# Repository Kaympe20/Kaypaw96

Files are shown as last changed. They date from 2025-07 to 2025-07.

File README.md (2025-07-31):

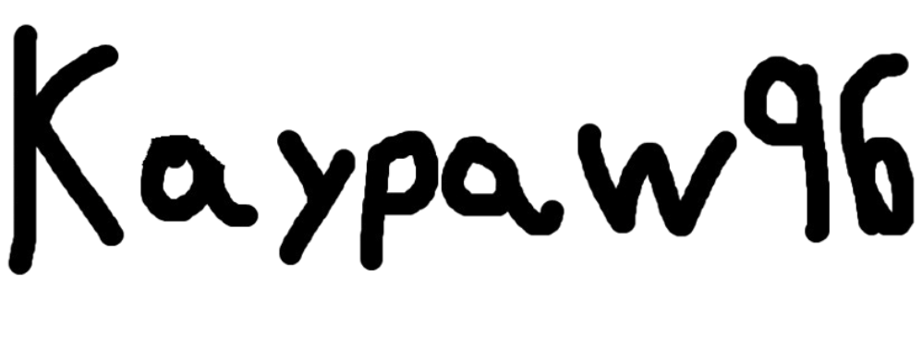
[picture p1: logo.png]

# Kaypaw96

<br>

A Southpaw 96% keyboard because numpads on the left are awesome
* They allow the keyboard to be centered on your desk.
* They let you use the mouse and numpad at the same time.
* They are plain more ergonomic.

---

[As featured on](https://highway.hackclub.com/projects/kaympe20/kaypaw96)

[](https://highway.hackclub.com/projects/kaympe20/kaypaw96)

---

I made this keyboard because, as an ambidextrous person, I often feel like my left hand is under-utilized while I am doing productivity, coding, and gaming. I also use a 75% and sometimes miss having more keys, so I wanted to make a keyboard that gave you nearly every key of a regular keyboard, plus 4 additional macro keys for things like sleep.

## Pics











## CAD

The entire CAD workspace can be found on [Onshape](https://cad.onshape.com/documents/bc15378757c65db7b8fb3e3b/w/9f716e622823b7e5e5c4b7e3/e/b78d5af8ee98cae8cd027468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)

## BOM

| Item | Quantity | Price | Price After Taxes + Shipping |
|---|---|---|---|
[Assembled PCB](https://github.com/Kaympe20/Kaypaw96/tree/main/production) | 1 | $81.58 | $169.13
[3D Printed Case](https://github.com/Kaympe20/Kaypaw96/blob/main/cad/Case.step) | 1 | $0 | $0
[Cherry MX Switches](https://www.amazon.com/Glorious-Gaming-Hotswappable-Mechanical-Keyboards/dp/B0DCPCS6CP) (cheapest I could find after shipping) | 110 | $31.99 | $33.91
[Keycap Set](https://www.amazon.com/Keycaps-Doubleshot-Percent-Mechanical-Keyboard/dp/B0D1QVD55F) | 1 | $16.86 | $17.87
[NCP1117-3.3_SOT223](https://www.amazon.com/PMMCON-AMS1117-LM1117-Voltage-Regulator/dp/B0BNY8KM87) | 1 | $9.99 | $10.59
[M3 Hardware](https://www.amazon.com/420pcs-Premium-Printing-Assortment-Washers/dp/B0CSX4NX7R) | N/a | $6.99 | $7.41

Total: $238.91

Here's the parts I selected in JLCPCB:



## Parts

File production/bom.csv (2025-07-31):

Designator | Footprint | Quantity | Value | LCSC Part #
C1, C2 | C0402 | 2 | 15p
C10, C11, C12, C13, C14, C16, C6, C7, C8, C9 | C0402 | 10 | 100n
C100, C101, C102, C103, C104, C105, C106, C107, C109, C110, C111, C112, C113, C114, C115, C116, C117, C118, C25, C26, C27, C28, C29, C30, C40, C41, C42, C43, C44, C45, C55, C56, C57, C58, C59, C60, C70, C71, C72, C73, C74, C75, C84, C85, C86, C87, C88, C89, C90, C96, C97, C98, C99 | C0402 | 53 | 0.1u
C15, C5 | C0402 | 2 | 1u
C3, C4 | C0402 | 2 | 10u
D1, D10, D100, D101, D102, D103, D104, D105, D11, D12, D13, D14, D15, D16, D17, D18, D19, D2, D20, D21, D22, D23, D24, D25, D26, D27, D28, D29, D3, D30, D31, D32, D33, D34, D35, D36, D37, D38, D39, D4, D40, D41, D42, D43, D44, D45, D46, D47, D48, D49, D5, D50, D51, D52, D53, D54, D55, D56, D57, D58, D59, D6, D60, D61, D62, D63, D64, D65, D66, D67, D68, D69, D7, D70, D71, D72, D73, D74, D75, D76, D77, D78, D79, D8, D80, D81, D82, D83, D84, D85, D86, D87, D88, D89, D9, D90, D91, D92, D93, D94, D95, D96, D97, D98, D99 | RB161QS-40 | 105 | D
D106, D107, D108, D109, D110, D111, D112, D113, D114, D115, D116, D117, D118, D119, D120, D121, D122, D123, D124, D125, D126, D127, D128, D129, D130, D131, D132, D133, D134, D135, D136, D137, D138, D139, D140, D141, D142, D143, D144, D145, D146, D147, D148, D149, D150, D151, D152, D153, D154, D155, D156, D157, D158, D159, D160, D161, D162, D163, D164, D165, D166, D167, D168, D169, D170, D171, D172, D173, D174, D175, D176, D177, D178, D179, D180, D181, D182, D183, D184, D185, D186, D187, D188, D189, D190, D191, D192, D193, D194, D195, D196, D197, D198, D199, D200, D201, D202, D203, D204, D205, D206, D207, D208, D209, D210 | SK6812MINI-E | 105 | SK6812MINI
J1 | USB_C_Receptacle_XKB_U262-16XN-4BVC11 | 1 | USB_C_Receptacle_USB2.0_14P
J2 | HDR-TH_2P-P2.54-V-M | 1 | Conn_01x02
R1, R6 | 0402 | 2 | 1k
R2, R3 | 0402 | 2 | 5.1k
R4, R5 | 0402 | 2 | 27.4
SW1, SW10, SW100, SW101, SW102, SW103, SW104, SW105, SW11, SW12, SW13, SW14, SW15, SW16, SW17, SW18, SW19, SW2, SW20, SW21, SW22, SW23, SW24, SW25, SW26, SW27, SW28, SW29, SW3, SW30, SW31, SW32, SW33, SW34, SW35, SW37, SW38, SW39, SW4, SW40, SW41, SW43, SW44, SW45, SW46, SW47, SW48, SW49, SW5, SW50, SW51, SW52, SW53, SW54, SW55, SW56, SW57, SW58, SW59, SW6, SW60, SW61, SW62, SW63, SW64, SW65, SW66, SW67, SW68, SW69, SW7, SW70, SW71, SW72, SW73, SW75, SW76, SW77, SW78, SW79, SW8, SW82, SW83, SW84, SW85, SW86, SW87, SW88, SW89, SW9, SW90, SW91, SW92, SW93, SW94, SW95, SW96, SW97, SW98 | SW_Cherry_MX_1.00u_PCB | 99 | SW_Push_45deg
SW36, SW74, SW81 | SW_Cherry_MX_2.00u_PCB | 3 | SW_Push_45deg
SW42, SW80 | SW_Cherry_MX_2.00u_Vertical_PCB | 2 | SW_Push_45deg
SW99 | SW_Cherry_MX_6.25u_PCB | 1 | SW_Push_45deg
U1 | QFN-56-1EP_7x7mm_P0.4mm_EP3.2x3.2mm | 1 | RP2040
U2 | SOT-223-3_TabPin2 | 1 | NCP1117-3.3_SOT223
U3 | SOIC-8_5.3x5.3mm_P1.27mm | 1 | W25Q128JVS
Y1 | XTAL_ABM8-272-T3 | 1 | ABM8-272-T3

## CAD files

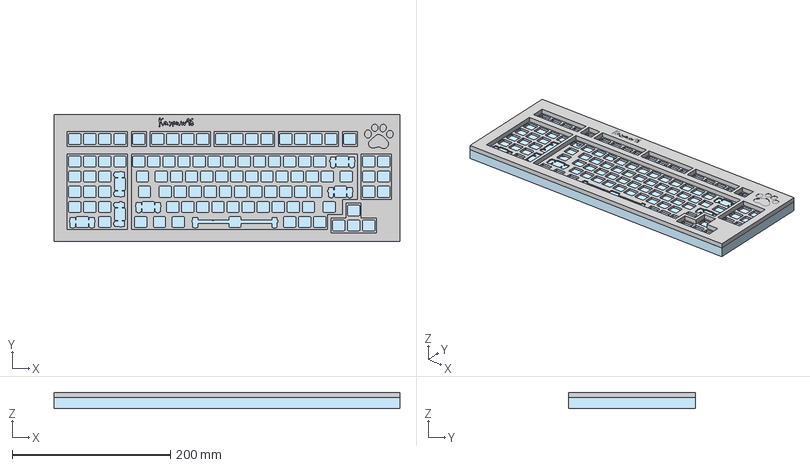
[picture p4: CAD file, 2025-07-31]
cad/Case.step
437.1 x 160.4 x 20.4 mm

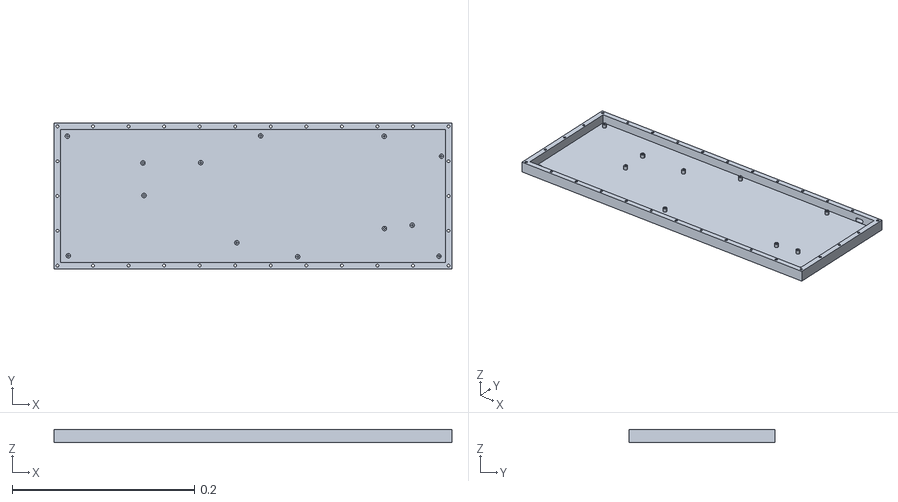
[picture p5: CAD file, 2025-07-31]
cad/STL/Case - Bottom.stl
0.437 x 0.16 x 0.0138

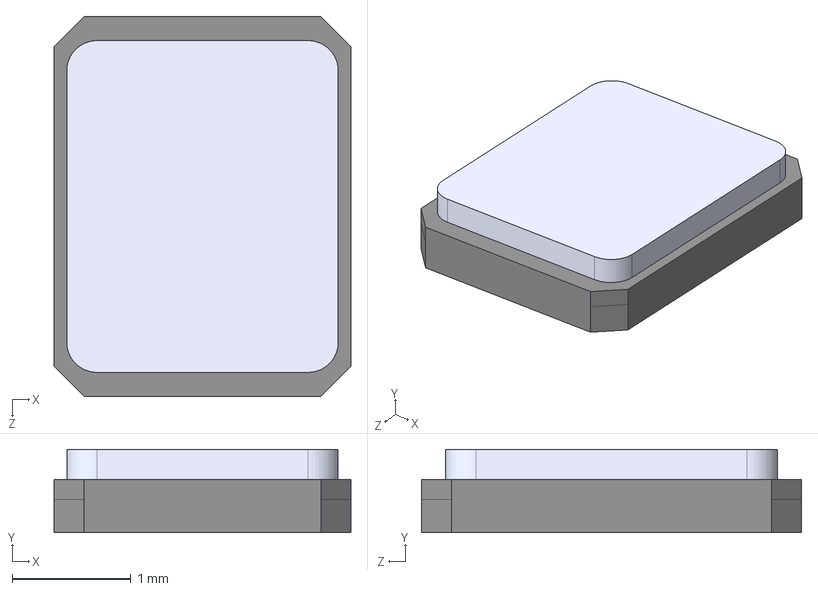
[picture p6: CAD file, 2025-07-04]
pcb/imports/ABM8-272-T3/ABM8-272-T3.step
2.50 x 0.7 x 3.20 mm

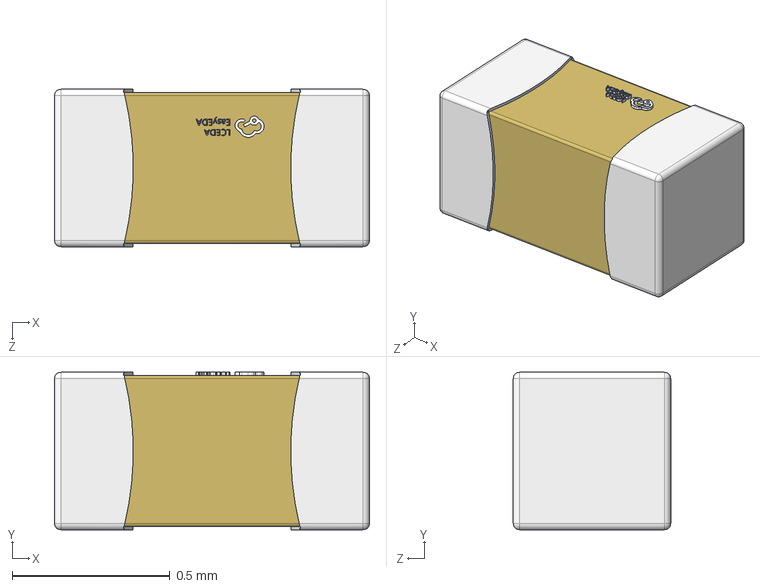
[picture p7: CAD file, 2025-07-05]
pcb/imports/CC0402FRNPO9BN150/C0402_L1.0-W0.5-H0.5.step
1.00 x 0.5 x 0.5 mm

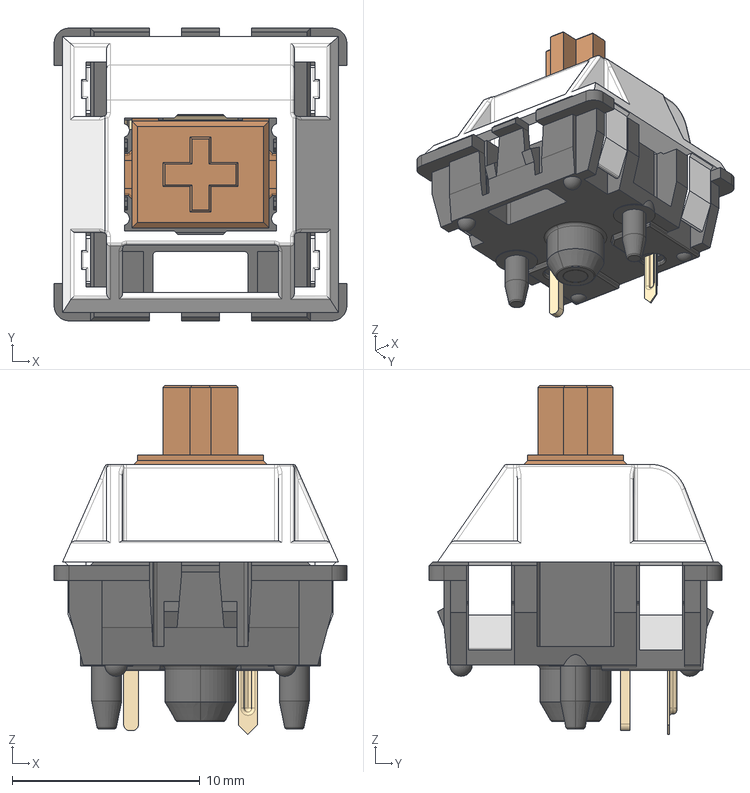
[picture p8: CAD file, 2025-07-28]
pcb/imports/Cherry MX Switch/SW_Cherry_MX_PCB.stp
15.6 x 15.6 x 18.6 mm

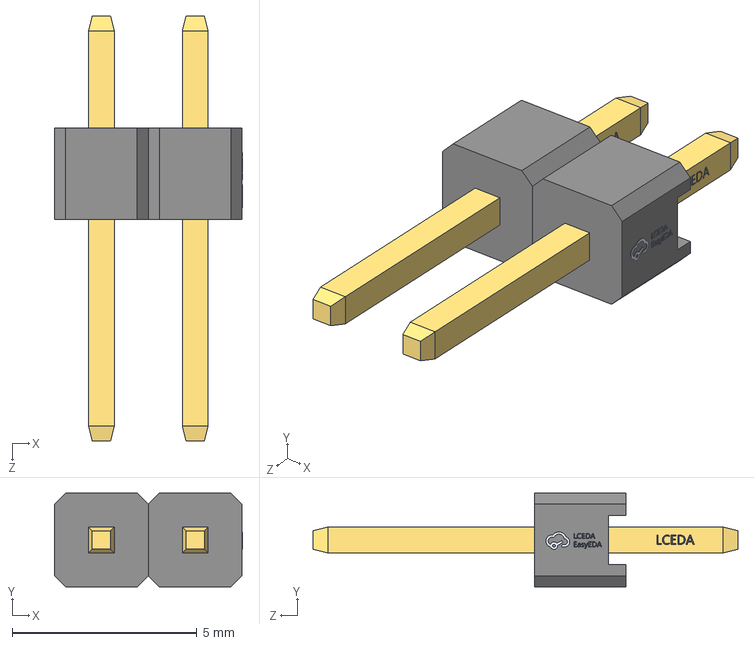
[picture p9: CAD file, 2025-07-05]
pcb/imports/PZ254V-11-02P/HDR2.54-M-LI-1X2P.step
5.09 x 2.54 x 11.5 mm

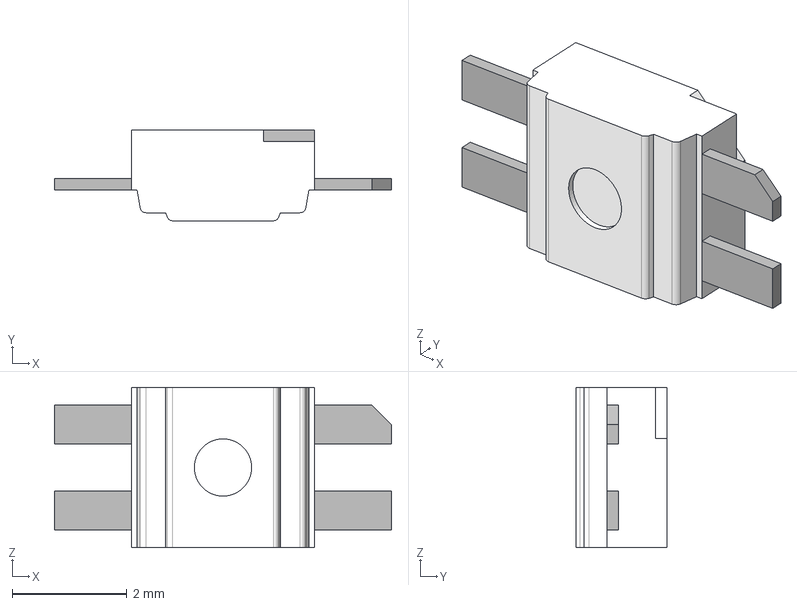
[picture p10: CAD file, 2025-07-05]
pcb/imports/SK6812-MINI Reverse/SK6812MINI-E.step
5.88 x 1.58 x 2.80 mm

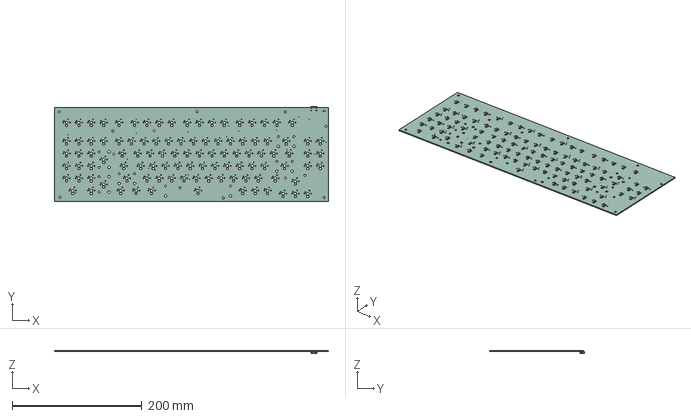
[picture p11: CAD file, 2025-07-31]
pcb/PCB.step
421.9 x 147.0 x 4.85 mm
USB-3.1-SMD_16P-L8.9-W7.3-H3.3-P0.5
kaypaw96_PCB

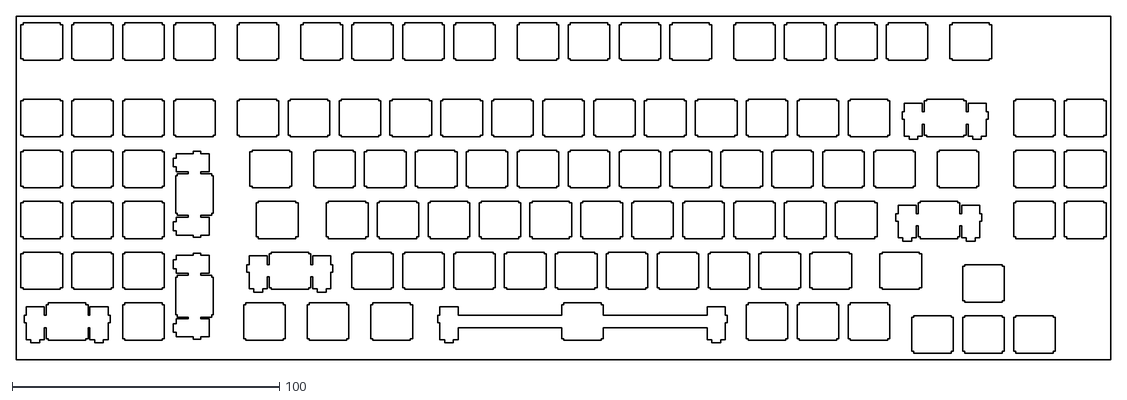
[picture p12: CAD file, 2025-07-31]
plate.dxf
409.6 x 128.6

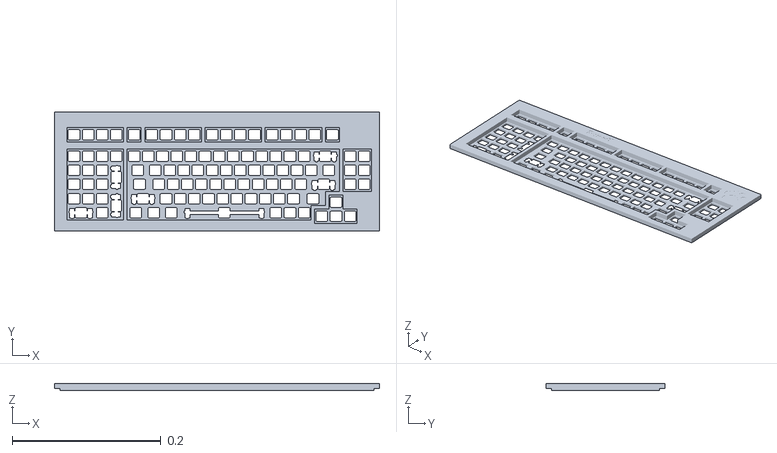
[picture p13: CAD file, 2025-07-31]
cad/STL/Case - Top.stl
0.437 x 0.16 x 0.0096

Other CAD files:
pcb/PCB without components.step

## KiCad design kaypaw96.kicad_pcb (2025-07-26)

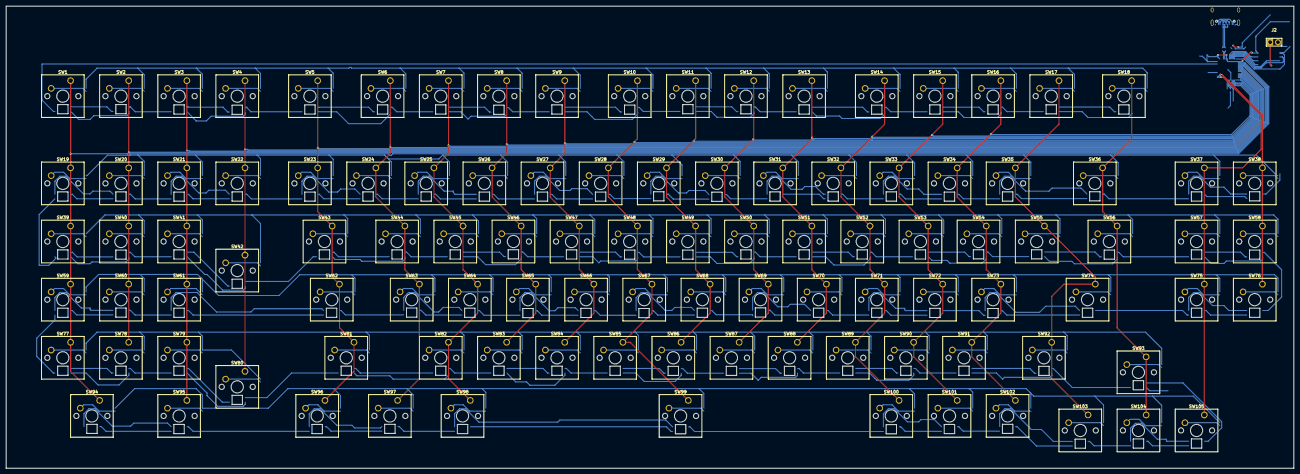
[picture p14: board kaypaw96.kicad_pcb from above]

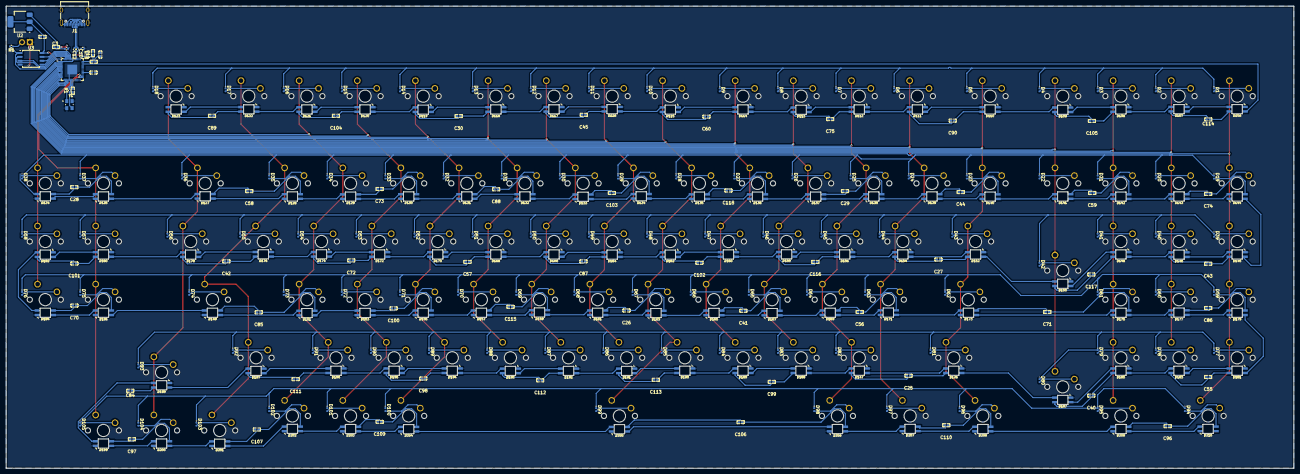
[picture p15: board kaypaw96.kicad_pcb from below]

Board: 2 copper layers, 421.9 x 151.4 mm, 388 parts (282 on the bottom side), 256 nets.

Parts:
C3: 10u; C0402
C8, C9, C10, C11, C12, C13, C14: 100n; C0402
C25, C26, C27, C28, C29, C30, C40, C41, C42, C43, C44, C45, C55, C56, C57, C58, C59, C60, C70, C71, C72, C73, C74, C75, C84, C85, C86, C87, C88, C89, C90, C96, C97, C98, C99, C100, C101, C102, C103, C104, C105, C106, C107, C109, C110, C111, C112, C113, C114, C115, C116, C117, C118: 0.1u; C0402
D1, D2, D3, D4, D5, D6, D7, D8, D9, D10, D11, D12, D13, D14, D15, D16, D17, D18, D19, D20, D21, D22, D23, D24, D25, D26, D27, D28, D29, D30, D31, D32, D33, D34, D35, D36, D37, D38, D39, D40, D41, D42, D43, D44, D45, D46, D47, D48, D49, D50, D51, D52, D53, D54, D55, D56, D57, D58, D59, D60, D61, D62, D63, D64, D65, D66, D67, D68, D69, D70, D71, D72, D73, D74, D75, D76, D77, D78, D79, D80, D81, D82, D83, D84, D85, D86, D87, D88, D89, D90, D91, D92, D93, D94, D95, D96, D97, D98, D99, D100, D101, D102, D103, D104, D105: D; RB161QS-40
D106, D107, D108, D109, D110, D111, D112, D113, D114, D115, D116, D117, D118, D119, D120, D121, D122, D123, D124, D125, D126, D127, D128, D129, D130, D131, D132, D133, D134, D135, D136, D137, D138, D139, D140, D141, D142, D143, D144, D145, D146, D147, D148, D149, D150, D151, D152, D153, D154, D155, D156, D157, D158, D159, D160, D161, D162, D163, D164, D165, D166, D167, D168, D169, D170, D171, D172, D173, D174, D175, D176, D177, D178, D179, D180, D181, D182, D183, D184, D185, D186, D187, D188, D189, D190, D191, D192, D193, D194, D195, D196, D197, D198, D199, D200, D201, D202, D203, D204, D205, D206, D207, D208, D209, D210: SK6812MINI; SK6812MINI-E
J1: USB_C_Receptacle_USB2.0_14P; USB_C_Receptacle_XKB_U262-16XN-4BVC11
J2: Conn_01x02; HDR-TH_2P-P2.54-V-M
R1, R6: 1k; R_0402_1005Metric
R2, R3: 5.1k; R_0402_1005Metric
R4, R5: 27.4; R_0402_1005Metric
SW1, SW2, SW3, SW4, SW5, SW6, SW7, SW8, SW9, SW10, SW11, SW12, SW13, SW14, SW15, SW16, SW17, SW18, SW19, SW20, SW21, SW22, SW23, SW24, SW25, SW26, SW27, SW28, SW29, SW30, SW31, SW32, SW33, SW34, SW35, SW36, SW37, SW38, SW39, SW40, SW41, SW42, SW43, SW44, SW45, SW46, SW47, SW48, SW49, SW50, SW51, SW52, SW53, SW54, SW55, SW56, SW57, SW58, SW59, SW60, SW61, SW62, SW63, SW64, SW65, SW66, SW67, SW68, SW69, SW70, SW71, SW72, SW73, SW74, SW75, SW76, SW77, SW78, SW79, SW80, SW81, SW82, SW83, SW84, SW85, SW86, SW87, SW88, SW89, SW90, SW91, SW92, SW93, SW94, SW95, SW96, SW97, SW98, SW99, SW100, SW101, SW102, SW103, SW104, SW105: SW_Push_45deg; SW_Cherry_MX_1.00u_PCB
U1: RP2040; QFN-56-1EP_7x7mm_P0.4mm_EP3.2x3.2mm
U2: NCP1117-3.3_SOT223; SOT-223-3_TabPin2
U3: W25Q128JVS; SOIC-8_5.3x5.3mm_P1.27mm
Y1: ABM8-272-T3; XTAL_ABM8-272-T3

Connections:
+1V1: U1.23 (DVDD), U1.45 (VREG_VOUT), U1.50 (DVDD)
+3.3V: C8.1, C9.1, C10.1, C11.1, C12.1, C13.1, C14.1, U1.1 (IOVDD), U1.10 (IOVDD), U1.22 (IOVDD), U1.33 (IOVDD), U1.42 (IOVDD), U1.43 (ADC_AVDD), U1.44 (VREG_IN), U1.48 (USB_VDD), U1.49 (IOVDD), U2.2 (VO), U3.8 (VCC)
+5V: C3.1, C25.1, C26.1, C27.1, C28.1, C29.1, C30.1, C40.1, C41.1, C42.1, C43.1, C44.1, C45.1, C55.1, C56.1, C57.1, C58.1, C59.1, C60.1, C70.1, C71.1, C72.1, C73.1, C74.1, C75.1, C84.1, C85.1, C86.1, C87.1, C88.1, C89.1, C90.1, C96.1, C97.1, C98.1, C99.1, C100.1, C101.1, C102.1, C103.1, C104.1, C105.1, C106.1, C107.1, C109.1, C110.1, C111.1, C112.1, C113.1, C114.1, C115.1, C116.1, C117.1, C118.1, D106.4 (VDD), D107.4 (VDD), D108.4 (VDD), D109.4 (VDD), D110.4 (VDD), D111.4 (VDD), D112.4 (VDD), D113.4 (VDD), D114.4 (VDD), D115.4 (VDD), D116.4 (VDD), D117.4 (VDD), D118.4 (VDD), D119.4 (VDD), D120.4 (VDD), D121.4 (VDD), D122.4 (VDD), D123.4 (VDD), D124.4 (VDD), D125.4 (VDD), D126.4 (VDD), D127.4 (VDD), D128.4 (VDD), D129.4 (VDD), D130.4 (VDD), D131.4 (VDD), D132.4 (VDD), D133.4 (VDD), D134.4 (VDD), D135.4 (VDD), D136.4 (VDD), D137.4 (VDD), D138.4 (VDD), D139.4 (VDD), D140.4 (VDD), D141.4 (VDD), D142.4 (VDD), D143.4 (VDD), D144.4 (VDD), D145.4 (VDD), D146.4 (VDD), D147.4 (VDD), D148.4 (VDD), D149.4 (VDD), D150.4 (VDD), D151.4 (VDD), D152.4 (VDD), D153.4 (VDD), D154.4 (VDD), D155.4 (VDD), D156.4 (VDD), D157.4 (VDD), D158.4 (VDD), D159.4 (VDD), D160.4 (VDD), D161.4 (VDD), D162.4 (VDD), D163.4 (VDD), D164.4 (VDD), D165.4 (VDD), D166.4 (VDD), D167.4 (VDD), D168.4 (VDD), D169.4 (VDD), D170.4 (VDD), D171.4 (VDD), D172.4 (VDD), D173.4 (VDD), D174.4 (VDD), D175.4 (VDD), D176.4 (VDD), D177.4 (VDD), D178.4 (VDD), D179.4 (VDD), D180.4 (VDD), D181.4 (VDD), D182.4 (VDD), D183.4 (VDD), D184.4 (VDD), D185.4 (VDD), D186.4 (VDD), D187.4 (VDD), D188.4 (VDD), D189.4 (VDD), D190.4 (VDD), D191.4 (VDD), D192.4 (VDD), D193.4 (VDD), D194.4 (VDD), D195.4 (VDD), D196.4 (VDD), D197.4 (VDD), D198.4 (VDD), D199.4 (VDD), D200.4 (VDD), D201.4 (VDD), D202.4 (VDD), D203.4 (VDD), D204.4 (VDD), D205.4 (VDD), D206.4 (VDD), D207.4 (VDD), D208.4 (VDD), D209.4 (VDD), D210.4 (VDD), J1.A4 (VBUS), J1.A9 (VBUS), J1.B4 (VBUS), J1.B9 (VBUS), U2.3 (VI)
/QSPI_SCLK: U1.52 (QSPI_SCLK), U3.6 (CLK)
/QSPI_SD0: U1.53 (QSPI_SD0), U3.5 (DI/IO_{0})
/QSPI_SD1: U1.55 (QSPI_SD1), U3.2 (DO/IO_{1})
/QSPI_SD2: U1.54 (QSPI_SD2), U3.3 (~WP/IO_{2})
/QSPI_SD3: U1.51 (QSPI_SD3), U3.7 (~HOLD/~RESET/IO_{3})
/QSPI_SS: R6.2, U1.56 (QSPI_SS), U3.1 (~CS)
Col 1: SW1.1, SW19.1, SW39.1, SW59.1, SW77.1, SW94.1, U1.2 (GPIO0)
Col 2: SW2.1, SW20.1, SW40.1, SW60.1, SW78.1, U1.3 (GPIO1)
Col 3: SW3.1, SW21.1, SW41.1, SW61.1, SW79.1, SW95.1, U1.4 (GPIO2)
Col 4: SW4.1, SW22.1, SW42.1, SW80.1, U1.5 (GPIO3)
Col 5: SW5.1, SW23.1, SW43.1, SW62.1, SW81.1, SW96.1, U1.6 (GPIO4)
Col 6: SW6.1, SW24.1, SW44.1, SW63.1, SW97.1, U1.7 (GPIO5)
Col 7: SW7.1, SW25.1, SW45.1, SW64.1, SW82.1, SW98.1, U1.8 (GPIO6)
Col 8: SW8.1, SW26.1, SW46.1, SW65.1, SW83.1, U1.9 (GPIO7)
Col 9: SW9.1, SW27.1, SW47.1, SW66.1, SW84.1, U1.11 (GPIO8)
Col 10: SW10.1, SW28.1, SW48.1, SW67.1, SW85.1, SW99.1, U1.12 (GPIO9)
Col 11: SW11.1, SW29.1, SW49.1, SW68.1, SW86.1, U1.13 (GPIO10)
Col 12: SW12.1, SW30.1, SW50.1, SW69.1, SW87.1, U1.14 (GPIO11)
Col 13: SW13.1, SW31.1, SW51.1, SW70.1, SW88.1, U1.15 (GPIO12)
Col 14: SW14.1, SW32.1, SW52.1, SW71.1, SW89.1, SW100.1, U1.16 (GPIO13)
Col 15: SW15.1, SW33.1, SW53.1, SW72.1, SW90.1, SW101.1, U1.17 (GPIO14)
Col 16: SW16.1, SW34.1, SW54.1, SW73.1, SW91.1, SW102.1, U1.18 (GPIO15)
Col 17: SW17.1, SW35.1, SW55.1, SW74.1, SW92.1, SW103.1, U1.27 (GPIO16)
Col 18: SW18.1, SW36.1, SW56.1, SW93.1, SW104.1, U1.28 (GPIO17)
Col 19: SW37.1, SW57.1, SW75.1, SW105.1, U1.29 (GPIO18)
Col 20: SW38.1, SW58.1, SW76.1, U1.30 (GPIO19)
D+: J1.A6 (D+), J1.B6 (D+), R4.1
D-: J1.A7 (D-), J1.B7 (D-), R5.1
GND: C3.2, C8.2, C9.2, C10.2, C11.2, C12.2, C13.2, C14.2, C25.2, C26.2, C27.2, C28.2, C29.2, C30.2, C40.2, C41.2, C42.2, C43.2, C44.2, C45.2, C55.2, C56.2, C57.2, C58.2, C59.2, C60.2, C70.2, C71.2, C72.2, C73.2, C74.2, C75.2, C84.2, C85.2, C86.2, C87.2, C88.2, C89.2, C90.2, C96.2, C97.2, C98.2, C99.2, C100.2, C101.2, C102.2, C103.2, C104.2, C105.2, C106.2, C107.2, C109.2, C110.2, C111.2, C112.2, C113.2, C114.2, C115.2, C116.2, C117.2, C118.2, D106.2 (VSS), D107.2 (VSS), D108.2 (VSS), D109.2 (VSS), D110.2 (VSS), D111.2 (VSS), D112.2 (VSS), D113.2 (VSS), D114.2 (VSS), D115.2 (VSS), D116.2 (VSS), D117.2 (VSS), D118.2 (VSS), D119.2 (VSS), D120.2 (VSS), D121.2 (VSS), D122.2 (VSS), D123.2 (VSS), D124.2 (VSS), D125.2 (VSS), D126.2 (VSS), D127.2 (VSS), D128.2 (VSS), D129.2 (VSS), D130.2 (VSS), D131.2 (VSS), D132.2 (VSS), D133.2 (VSS), D134.2 (VSS), D135.2 (VSS), D136.2 (VSS), D137.2 (VSS), D138.2 (VSS), D139.2 (VSS), D140.2 (VSS), D141.2 (VSS), D142.2 (VSS), D143.2 (VSS), D144.2 (VSS), D145.2 (VSS), D146.2 (VSS), D147.2 (VSS), D148.2 (VSS), D149.2 (VSS), D150.2 (VSS), D151.2 (VSS), D152.2 (VSS), D153.2 (VSS), D154.2 (VSS), D155.2 (VSS), D156.2 (VSS), D157.2 (VSS), D158.2 (VSS), D159.2 (VSS), D160.2 (VSS), D161.2 (VSS), D162.2 (VSS), D163.2 (VSS), D164.2 (VSS), D165.2 (VSS), D166.2 (VSS), D167.2 (VSS), D168.2 (VSS), D169.2 (VSS), D170.2 (VSS), D171.2 (VSS), D172.2 (VSS), D173.2 (VSS), D174.2 (VSS), D175.2 (VSS), D176.2 (VSS), D177.2 (VSS), D178.2 (VSS), D179.2 (VSS), D180.2 (VSS), D181.2 (VSS), D182.2 (VSS), D183.2 (VSS), D184.2 (VSS), D185.2 (VSS), D186.2 (VSS), D187.2 (VSS), D188.2 (VSS), D189.2 (VSS), D190.2 (VSS), D191.2 (VSS), D192.2 (VSS), D193.2 (VSS), D194.2 (VSS), D195.2 (VSS), D196.2 (VSS), D197.2 (VSS), D198.2 (VSS), D199.2 (VSS), D200.2 (VSS), D201.2 (VSS), D202.2 (VSS), D203.2 (VSS), D204.2 (VSS), D205.2 (VSS), D206.2 (VSS), D207.2 (VSS), D208.2 (VSS), D209.2 (VSS), D210.2 (VSS), J1.A1 (GND), J1.A12 (GND), J1.B1 (GND), J1.B12 (GND), J1.S1 (SHIELD), J2.1, R2.2, R3.2, U1.19 (TESTEN), U1.57 (GND), U2.1 (GND), U3.4 (GND), Y1.2 (GND), Y1.4 (GND)
NEO: D106.3 (DIN), U1.40 (GPIO28_ADC2)
unnamed: R1.1, Y1.3
unnamed: D1.2 (A), SW1.2
unnamed: D2.2 (A), SW2.2
unnamed: D3.2 (A), SW3.2
unnamed: D4.2 (A), SW4.2
unnamed: D5.2 (A), SW5.2
unnamed: D6.2 (A), SW6.2
unnamed: D7.2 (A), SW7.2
unnamed: D8.2 (A), SW8.2
unnamed: D9.2 (A), SW9.2
unnamed: D10.2 (A), SW10.2
unnamed: D11.2 (A), SW11.2
unnamed: D12.2 (A), SW12.2
unnamed: D13.2 (A), SW13.2
unnamed: D14.2 (A), SW14.2
unnamed: D15.2 (A), SW15.2
unnamed: D16.2 (A), SW16.2
unnamed: D17.2 (A), SW17.2
unnamed: D18.2 (A), SW18.2
unnamed: D19.2 (A), SW19.2
unnamed: D20.2 (A), SW20.2
unnamed: D21.2 (A), SW21.2
unnamed: D22.2 (A), SW22.2
unnamed: D23.2 (A), SW23.2
unnamed: D24.2 (A), SW24.2
unnamed: D25.2 (A), SW25.2
unnamed: D26.2 (A), SW26.2
unnamed: D27.2 (A), SW27.2
unnamed: D28.2 (A), SW28.2
unnamed: D29.2 (A), SW29.2
unnamed: D30.2 (A), SW30.2
unnamed: D31.2 (A), SW31.2
unnamed: D32.2 (A), SW32.2
unnamed: D33.2 (A), SW33.2
unnamed: D34.2 (A), SW34.2
unnamed: D35.2 (A), SW35.2
unnamed: D36.2 (A), SW36.2
unnamed: D37.2 (A), SW37.2
unnamed: D38.2 (A), SW38.2
unnamed: D39.2 (A), SW39.2
unnamed: D40.2 (A), SW40.2
unnamed: D41.2 (A), SW41.2
unnamed: D42.2 (A), SW42.2
unnamed: D43.2 (A), SW43.2
unnamed: D44.2 (A), SW44.2
unnamed: D45.2 (A), SW45.2
unnamed: D46.2 (A), SW46.2
unnamed: D47.2 (A), SW47.2
unnamed: D48.2 (A), SW48.2
unnamed: D49.2 (A), SW49.2
unnamed: D50.2 (A), SW50.2
unnamed: D51.2 (A), SW51.2
unnamed: D52.2 (A), SW52.2
unnamed: D53.2 (A), SW53.2
unnamed: D54.2 (A), SW54.2
unnamed: D55.2 (A), SW55.2
unnamed: D56.2 (A), SW56.2
unnamed: D57.2 (A), SW57.2
unnamed: D58.2 (A), SW58.2
unnamed: D59.2 (A), SW59.2
unnamed: D60.2 (A), SW60.2
unnamed: D61.2 (A), SW61.2
unnamed: D62.2 (A), SW62.2
unnamed: D63.2 (A), SW63.2
unnamed: D64.2 (A), SW64.2
unnamed: D65.2 (A), SW65.2
unnamed: D66.2 (A), SW66.2
unnamed: D67.2 (A), SW67.2
unnamed: D68.2 (A), SW68.2
unnamed: D69.2 (A), SW69.2
unnamed: D70.2 (A), SW70.2
unnamed: D71.2 (A), SW71.2
unnamed: D72.2 (A), SW72.2
unnamed: D73.2 (A), SW73.2
unnamed: D74.2 (A), SW74.2
unnamed: D75.2 (A), SW75.2
unnamed: D76.2 (A), SW76.2
unnamed: D77.2 (A), SW77.2
unnamed: D78.2 (A), SW78.2
unnamed: D79.2 (A), SW79.2
unnamed: D80.2 (A), SW80.2
unnamed: D81.2 (A), SW81.2
unnamed: D82.2 (A), SW82.2
unnamed: D83.2 (A), SW83.2
unnamed: D84.2 (A), SW84.2
unnamed: D85.2 (A), SW85.2
unnamed: D86.2 (A), SW86.2
unnamed: D87.2 (A), SW87.2
unnamed: D88.2 (A), SW88.2
unnamed: D89.2 (A), SW89.2
unnamed: D90.2 (A), SW90.2
unnamed: D91.2 (A), SW91.2
unnamed: D92.2 (A), SW92.2
unnamed: D93.2 (A), SW93.2
unnamed: D94.2 (A), SW94.2
unnamed: D95.2 (A), SW95.2
unnamed: D96.2 (A), SW96.2
unnamed: D97.2 (A), SW97.2
unnamed: D98.2 (A), SW98.2
unnamed: D99.2 (A), SW99.2
unnamed: D100.2 (A), SW100.2
unnamed: D101.2 (A), SW101.2
unnamed: D102.2 (A), SW102.2
unnamed: D103.2 (A), SW103.2
unnamed: D104.2 (A), SW104.2
unnamed: D105.2 (A), SW105.2
unnamed: D106.1 (DOUT), D107.3 (DIN)
unnamed: D107.1 (DOUT), D108.3 (DIN)
unnamed: D108.1 (DOUT), D109.3 (DIN)
unnamed: D109.1 (DOUT), D110.3 (DIN)
unnamed: D110.1 (DOUT), D111.3 (DIN)
unnamed: D111.1 (DOUT), D112.3 (DIN)
unnamed: D112.1 (DOUT), D113.3 (DIN)
unnamed: D113.1 (DOUT), D114.3 (DIN)
unnamed: D114.1 (DOUT), D115.3 (DIN)
unnamed: D115.1 (DOUT), D116.3 (DIN)
unnamed: D116.1 (DOUT), D117.3 (DIN)
unnamed: D117.1 (DOUT), D118.3 (DIN)
unnamed: D118.1 (DOUT), D119.3 (DIN)
unnamed: D119.1 (DOUT), D120.3 (DIN)
unnamed: D120.1 (DOUT), D121.3 (DIN)
unnamed: D121.1 (DOUT), D122.3 (DIN)
unnamed: D122.1 (DOUT), D123.3 (DIN)
unnamed: D123.1 (DOUT), D124.3 (DIN)
unnamed: D124.1 (DOUT), D125.3 (DIN)
unnamed: D125.1 (DOUT), D127.3 (DIN)
unnamed: D126.3 (DIN), D187.1 (DOUT)
unnamed: D126.1 (DOUT), D147.3 (DIN)
unnamed: D127.1 (DOUT), D128.3 (DIN)
unnamed: D128.1 (DOUT), D129.3 (DIN)
unnamed: D129.1 (DOUT), D130.3 (DIN)
unnamed: D130.1 (DOUT), D131.3 (DIN)
unnamed: D131.1 (DOUT), D132.3 (DIN)
unnamed: D132.1 (DOUT), D133.3 (DIN)
unnamed: D133.1 (DOUT), D134.3 (DIN)
unnamed: D134.1 (DOUT), D135.3 (DIN)
unnamed: D135.1 (DOUT), D136.3 (DIN)
unnamed: D136.1 (DOUT), D137.3 (DIN)
unnamed: D137.1 (DOUT), D138.3 (DIN)
unnamed: D138.1 (DOUT), D139.3 (DIN)
unnamed: D139.1 (DOUT), D140.3 (DIN)
unnamed: D140.1 (DOUT), D141.3 (DIN)
unnamed: D141.1 (DOUT), D142.3 (DIN)
unnamed: D142.1 (DOUT), D143.3 (DIN)
unnamed: D143.1 (DOUT), D144.3 (DIN)
unnamed: D144.1 (DOUT), D145.3 (DIN)
unnamed: D145.1 (DOUT), D146.3 (DIN)
unnamed: D146.1 (DOUT), D148.3 (DIN)
unnamed: D147.1 (DOUT), D188.3 (DIN)
unnamed: D148.1 (DOUT), D150.3 (DIN)
unnamed: D149.3 (DIN), D186.1 (DOUT)
unnamed: D149.1 (DOUT), D151.3 (DIN)
unnamed: D150.1 (DOUT), D152.3 (DIN)
unnamed: D151.1 (DOUT), D153.3 (DIN)
unnamed: D152.1 (DOUT), D154.3 (DIN)
unnamed: D153.1 (DOUT), D155.3 (DIN)
unnamed: D154.1 (DOUT), D156.3 (DIN)
unnamed: D155.1 (DOUT), D157.3 (DIN)
unnamed: D156.1 (DOUT), D158.3 (DIN)
unnamed: D157.1 (DOUT), D159.3 (DIN)
unnamed: D158.1 (DOUT), D160.3 (DIN)
unnamed: D159.1 (DOUT), D161.3 (DIN)
unnamed: D160.1 (DOUT), D162.3 (DIN)
unnamed: D161.1 (DOUT), D163.3 (DIN)
unnamed: D162.1 (DOUT), D164.3 (DIN)
unnamed: D163.1 (DOUT), D165.3 (DIN)
unnamed: D164.1 (DOUT), D166.3 (DIN)
unnamed: D165.1 (DOUT), D167.3 (DIN)
unnamed: D166.1 (DOUT), D168.3 (DIN)
unnamed: D167.1 (DOUT), D169.3 (DIN)
unnamed: D168.1 (DOUT), D170.3 (DIN)
unnamed: D169.1 (DOUT), D171.3 (DIN)
unnamed: D170.1 (DOUT), D172.3 (DIN)
unnamed: D171.1 (DOUT), D173.3 (DIN)
unnamed: D172.1 (DOUT), D174.3 (DIN)
unnamed: D173.1 (DOUT), D175.3 (DIN)
unnamed: D174.1 (DOUT), D176.3 (DIN)
unnamed: D175.1 (DOUT), D177.3 (DIN)
unnamed: D176.1 (DOUT), D178.3 (DIN)
unnamed: D177.1 (DOUT), D179.3 (DIN)
unnamed: D178.1 (DOUT), D180.3 (DIN)
unnamed: D179.1 (DOUT), D181.3 (DIN)
unnamed: D180.1 (DOUT), D182.3 (DIN)
unnamed: D181.1 (DOUT), D183.3 (DIN)
unnamed: D182.1 (DOUT), D184.3 (DIN)
unnamed: D183.1 (DOUT), D185.3 (DIN)
unnamed: D184.1 (DOUT), D186.3 (DIN)
unnamed: D185.1 (DOUT), D187.3 (DIN)
unnamed: D188.1 (DOUT), D189.3 (DIN)
unnamed: D189.1 (DOUT), D190.3 (DIN)
unnamed: D190.1 (DOUT), D191.3 (DIN)
unnamed: D191.1 (DOUT), D192.3 (DIN)
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

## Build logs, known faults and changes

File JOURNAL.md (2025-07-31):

---
title: "Kaypaw96"
author: "Kayla Blosser aka @Kayla"
description: "A southpaw 96% keyboard"
created_at: "2024-07-03"
---

### **Total Time Spent: 43hr**

---

## July 4, 2025

I setup the layout using [keyboard-layout-editor](https://keyboard-layout-editor.com/)



Time Spent: 1hr

---

I created the basic layout of the keyswitches in the schematic after learning how matrixes work



... only to realize I need diodes.



Time Spent: 2hr

---

I wired up the matrix with labels



Time Spent: 1.5hr

---

The pico didn't have enough pins so I've begun work directly using the RP2040 using the [RP2040 hardware design datasheet](https://datasheets.raspberrypi.com/rp2040/hardware-design-with-rp2040.pdf).



Time Spent 3hr

---

I finished up the setup for the RP2040 including power delivery, USB communications, and 



Time Spent: 3.5 hr

---

I research JLC PCBA Extended and added all of the neopixels on a single pin that will draw 1.3A.



Time Spent: 1.5hr

---

## July 5, 2025

I got a dark theme to stop searing my eyes and got capacitors for the NeoPixels, as well as having to figure out that 0.1uF is the same as 100nF.



Time Spent: 2hr

---

I found 0805 capacitors of varying capcity on [LCSC](https://lcsc.com/), imported them using [`easyeda2kicad`](https://github.com/uPesy/easyeda2kicad.py). I then assigned each type to its respective item, before realizing that the ESR of 0805 capacitors is too much for the RP2040 and that I would need 0402 alternatives. After going back to get the diodes, I couldn't find footprints so I had to slightly modify the template 0402 footprint.



Time Spent: 3.5hr

---

I started designing the PCB and started the grueling wiring of each individual key and light. I want to cry 😢. My fingers and my soul are in pain.



Time Spent: 2.5hr

---

I finished adding all of the neopixels, all 105 of them 😢.



Time Spent: 1.5hr

---

## July 6, 2025

I added more capacitors as per the spec of the SK6812-MINI's... 52 of them. I love KiCAD 👍.



Time Spent: 1.5hr

---

## July 25, 2025

I started wiring everything to do with the microcontrollers and all of its additional parts. It got hectic and chaotic very quickly.



[@marios](https://github.com/GalaxyGamingBoy) recomended I do a ground pour so I used [my hackpad v2 docs backup](https://hackpad-v2-backup.pages.dev/advancedguide#ground%20pour) to learn how to do one and it started looking much better.



I then started on the rows and collumns, but was again having difficulty in figuring out how to route them without vias because they ruin signal integrity. Then I realized that the keys are binary and signal integrity/noise shouldn't be nearly enough to get to on from off. With that newfound knowledge, I routed all of them using at least 2 vias each.



Here's what the microcontroller section looks like:



Time Spent: 4.5 hr

---

## July 26, 2025

I finished the PCB!!!! 🎊🥳💃🎉📢📣 (almost, tomorrow I'll figure out the hole size I need for gasket mounting)

I did all of the requisite wiring and looked thorugh all of my DRC checkers to see if there was any major issues.

As per [@mra](https://github.com/MichaByte)'s suggestion, I set the ground fill to both sides and put in a bunch of vias to connect all of the unconnected areas (that I had to constantly change to no layers to check where the unconnected areas were).

I now have 0 unconnected areas, except for the sides of my heart, which is now broken after spending so much time on a keyboard that might not work.



I also had to add a few more decoupling capacitors as per the spec, which, as always, required a lot of rerouting.



Time Spent: 3.5hr

---

## July 27, 2025

I finished the mounting holes and added holes for stabalizers. Originally I wanted to forego using screws and wanted to do a gasket mounting setup, but with cost quickly becoming something I have to look out for, I'll leave the mounting holes, and get poron foam to laser cut at my local library should there be room in the budget.





Time Spent: 1hr

---

## July 29, 2025

I added some more mounting holes and altered the size to be much better matched to the actual size of m3 screws.



I also began CAD and started trying to figure out how to add a plate for my switches.



Time Spent: 1.5hr

---

The holes were intersecting the stabalizers so I changed the position which required redoing half of the work I did.







While I was working on that, I decided to go and switch the measurements to variables to allow me to change them *en mas* later if tolerances don't allow.



The grey "𝑓𝑥" indicates they are calculated instead of a set variable.

Time Spent: 2hr

---

## July 30, 2025

I looked at Joe Scotto's How to Design Mechanical Keyboard Plates and Cases [as reccomended by the hackpad guide](https://hackpad.hackclub.com/resources), and got a DXF of my keyboard layout.





Here's what extruding that plate gave me:



After that, I went and looked at this Keychron V1 product image and realized that there was the elevated sections where the weren't any surrounding keys.



So I sketched out all of the areas where the weren't any keys and dimensioned them using dimensions I found on this datasheet on Google Drive.



Here's what it looks like as a unit.



Then I added some mounting screw holes with a counterbore so the screw head wouldn't stick out.



Time Spent: 2.5hr

---

I added each switch (*one by one*) into Onshape so I could have a full render.

First with the function row



Then with the numpad:



and then just idk general area



Here's the fully setup:



(The different colors are from pulling the keycap models from different places.)

Time Spent: 2hr

---

I saw this video that told me to use [kbfirmware.com](https://kbfirmware.com/), so I imported my layout into it.



It did not import correctly at all, wrong number of cols and rows and some stuff isn't routed to the right place. Since you can't do bulk operations, I'll have to do something that's becoming something of a trend on this keyboard and do it one by one.



I then moved on to the keymap phase. The [QMK Keycode Docs](https://docs.qmk.fm/keycodes) were super easy to use and quite helpful.



The task took so time but this work layout made it so much more efficient to work on.



Time Spent: 1.5hr

---

## July 31, 2025

I went and did some light customization to really make this keyboard my own, including a logo made in MS paint:





Time Spent: 1hr

---

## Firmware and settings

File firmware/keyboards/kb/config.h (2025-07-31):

#ifndef CONFIG_H
#define CONFIG_H

#include "config_common.h"

/* USB Device descriptor parameter */
#define VENDOR_ID       0xFEED
#define PRODUCT_ID      0x6060
#define DEVICE_VER      0x0001
#define MANUFACTURER    qmkbuilder
#define PRODUCT         keyboard
#define DESCRIPTION     Keyboard

/* key matrix size */
#define MATRIX_ROWS 6
#define MATRIX_COLS 20

/* key matrix pins */
#define MATRIX_ROW_PINS { B0, B1, B2, B3, B4, B5 }
#define MATRIX_COL_PINS { B7, C0, C1, C2, C3, C4, C5, C6, C7, D0, D1, D2, D3, D4, D5, D6, D7, E0, E1, E2 }
#define UNUSED_PINS

/* COL2ROW or ROW2COL */
#define DIODE_DIRECTION COL2ROW

/* number of backlight levels */

#ifdef BACKLIGHT_PIN
#define BACKLIGHT_LEVELS 3
#endif

/* Set 0 if debouncing isn't needed */
#define DEBOUNCING_DELAY 5

/* Mechanical locking support. Use KC_LCAP, KC_LNUM or KC_LSCR instead in keymap */
#define LOCKING_SUPPORT_ENABLE

/* Locking resynchronize hack */
#define LOCKING_RESYNC_ENABLE

/* key combination for command */
#define IS_COMMAND() ( \
    keyboard_report->mods == (MOD_BIT(KC_LSHIFT) | MOD_BIT(KC_RSHIFT)) \
)

/* prevent stuck modifiers */
#define PREVENT_STUCK_MODIFIERS


#ifdef RGB_DI_PIN
#define RGBLIGHT_ANIMATIONS
#define RGBLED_NUM 0
#define RGBLIGHT_HUE_STEP 8
#define RGBLIGHT_SAT_STEP 8
#define RGBLIGHT_VAL_STEP 8
#endif

#endif

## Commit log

2025-07-04 Add autosave to KiCAD
2025-07-04 Finish out RP2040 setup
    [kaypaw96.kicad_sch]
2025-07-05 Add neopixels
    [kaypaw96.kicad_sch]
2025-07-05 Add all imports
    [C0402_L1.0-W0.5-H0.5.step, SK6812MINI-E.step]
2025-07-05 Add capacitors for the neopixels
    [kaypaw96.kicad_sch]
2025-07-05 Add footprints for everything
    [HDR2.54-M-LI-1X2P.step, kaypaw96.kicad_pcb, kaypaw96.kicad_sch]
2025-07-06 Start PCB design
    [kaypaw96.kicad_pcb, kaypaw96.kicad_sch, plate-2025-07-05T21_04_31.704Z.dxf]
2025-07-06 Add all neopixels
    [kaypaw96.kicad_sch]
2025-07-06 Add more capacitors
    [kaypaw96.kicad_pcb]
2025-07-06 Update JOURNAL with capacitors
2025-07-06 remove kicad_prl from gitignore
2025-07-26 Route rows and cols as well as getting microcontroller and accessories wired up
    [kaypaw96.kicad_pcb, kaypaw96.kicad_sch]
2025-07-26 Finish PCB design
    [kaypaw96.kicad_sch]
2025-07-27 Finish PCB (for real this time)
2025-07-28 Add STEP file
    [SW_Cherry_MX_PCB.stp]
2025-07-30 Begin CAD and adjust mounting holes
    [PCB without components.step]
2025-07-31 Update CAD to status as of 7/30/2025
    [plate-2025-07-05T21_04_31.704Z.dxf, plate.dxf]
2025-07-31 Move PCB to pcb/
    [ABM8-272-T3.step, C0402_L1.0-W0.5-H0.5.step, HDR2.54-M-LI-1X2P.step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]
2025-07-31 Update PCB
2025-07-31 Remove csv from gitignore
    [bom.csv, designators.csv, positions.csv]
2025-07-31 Add CAD
    [Case - Bottom.stl, Case - Top.stl, Case.step]
2025-07-31 Add changes needed before submission
    [BOM.csv]
